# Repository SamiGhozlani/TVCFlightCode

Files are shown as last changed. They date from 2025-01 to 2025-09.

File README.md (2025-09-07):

# TVCFlightCode

Welcome to my Repo for my Thrust Vector Controlled model rocket.\
For my flight computer, I used an Arduino Nano, a BNO055 IMU, a 1528-1462-ND microSD card reader, and an MPM3610 buck converter among other things (see Pcb schematic for more details).\
Attatched is my flight code, the PCB schematic (developed with Altium), and the SolidWorks files.\
Below is a slow-mo of the first nominal flight.

rocket

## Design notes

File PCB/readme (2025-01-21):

# I sent my Gerber Files to JLCPCB for manufacturing

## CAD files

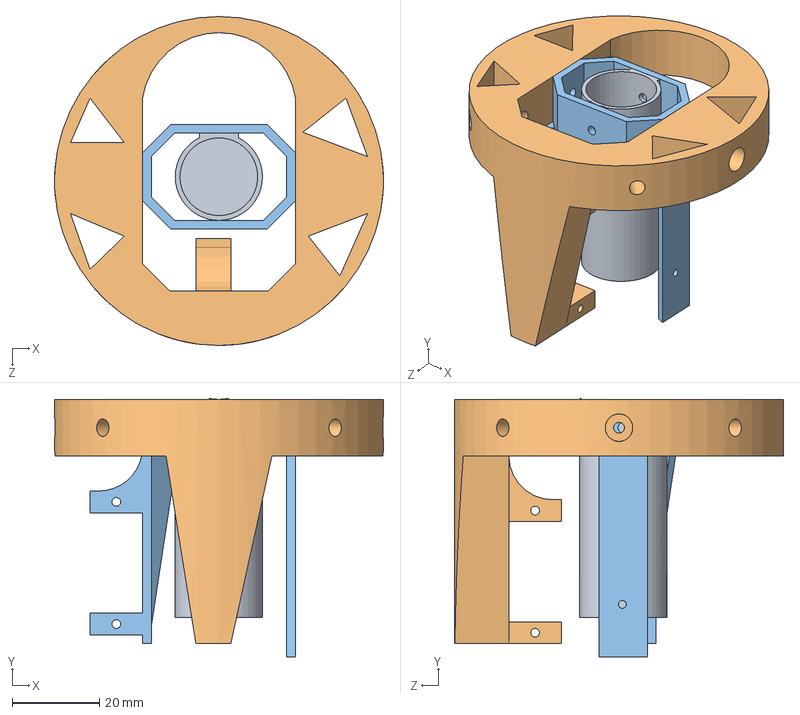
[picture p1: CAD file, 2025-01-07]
SolidWorks/AssemblyTVCMount.SLDASM
75.4 x 59.3 x 75.4 mm
Axis1TVM
Axis2
motorcase2

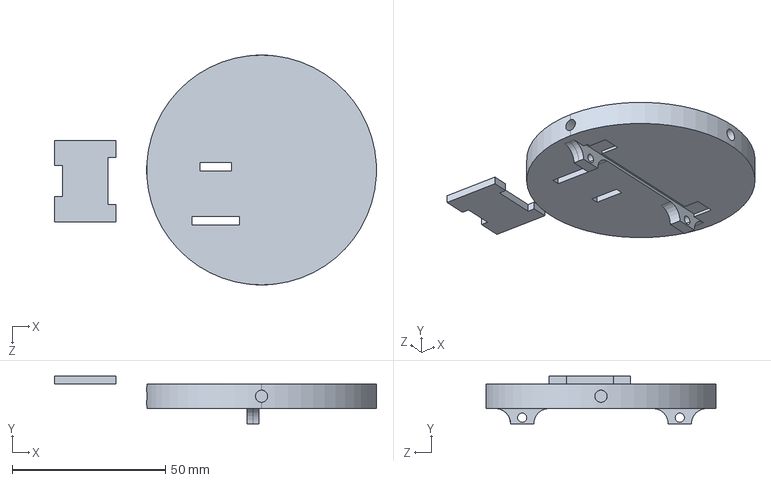
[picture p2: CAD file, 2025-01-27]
SolidWorks/BNOHolderTop.SLDPRT
105.1 x 15.5 x 75.0 mm

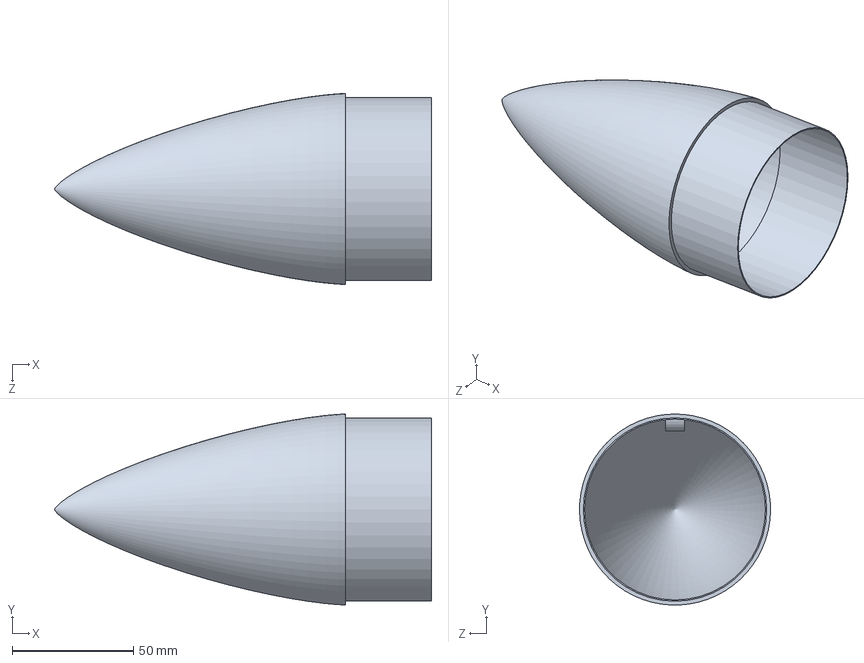
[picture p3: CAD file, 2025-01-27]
SolidWorks/NoseCone.SLDPRT
155.5 x 78.8 x 78.8 mm

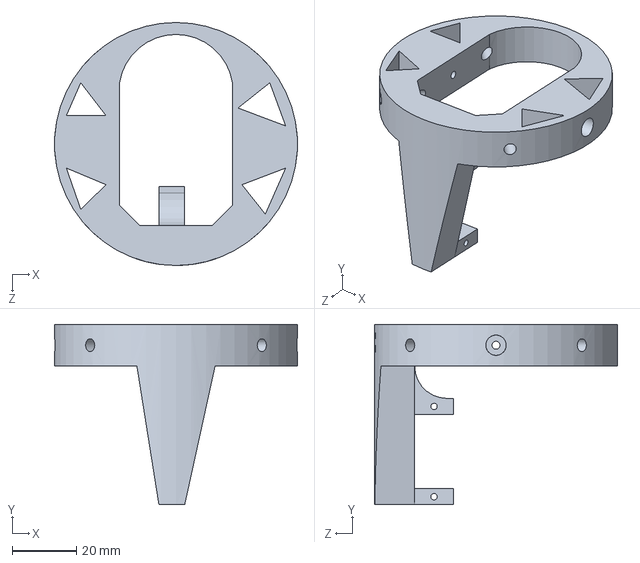
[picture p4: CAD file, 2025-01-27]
SolidWorks/Axis2.SLDPRT
75.4 x 56.0 x 75.4 mm

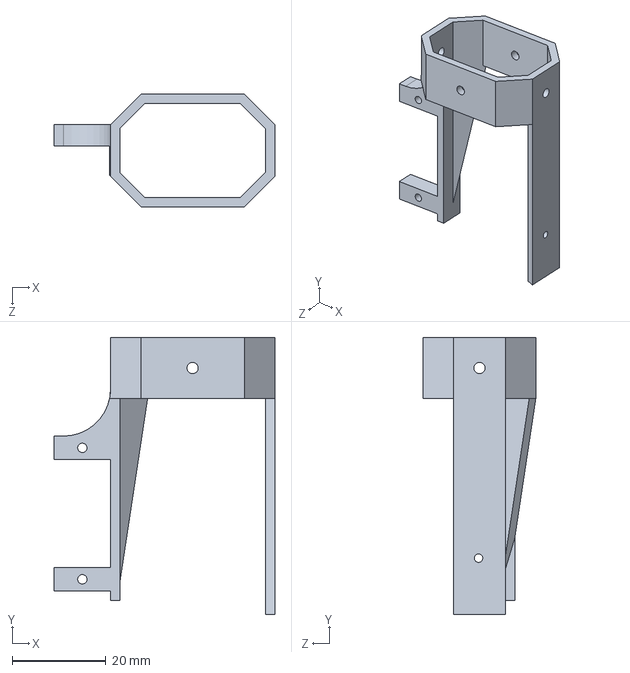
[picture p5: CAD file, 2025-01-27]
SolidWorks/Axis1TVM.SLDPRT
47.0 x 59.0 x 24.0 mm

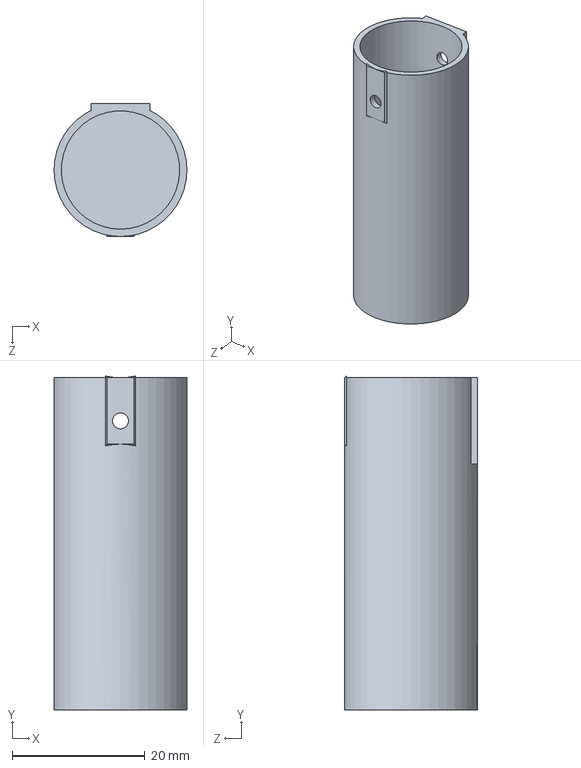
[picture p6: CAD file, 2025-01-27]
SolidWorks/motorcase2.SLDPRT
20.0 x 50.3 x 20.0 mm

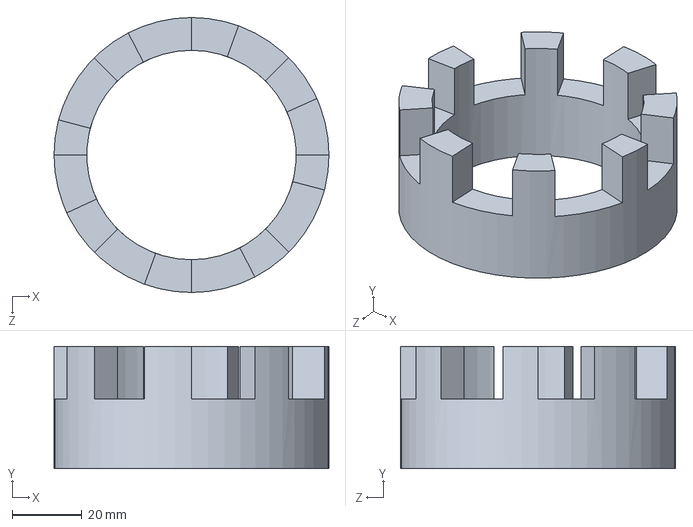
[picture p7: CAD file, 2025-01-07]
SolidWorks/LaunchMount.SLDPRT
78.8 x 35.0 x 78.8 mm

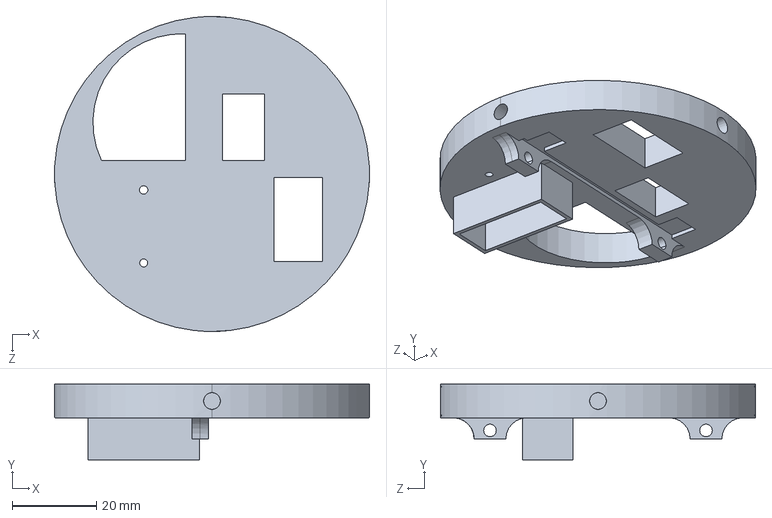
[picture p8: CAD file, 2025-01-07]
SolidWorks/PCBHolderBottom.SLDPRT
75.0 x 18.0 x 75.0 mm

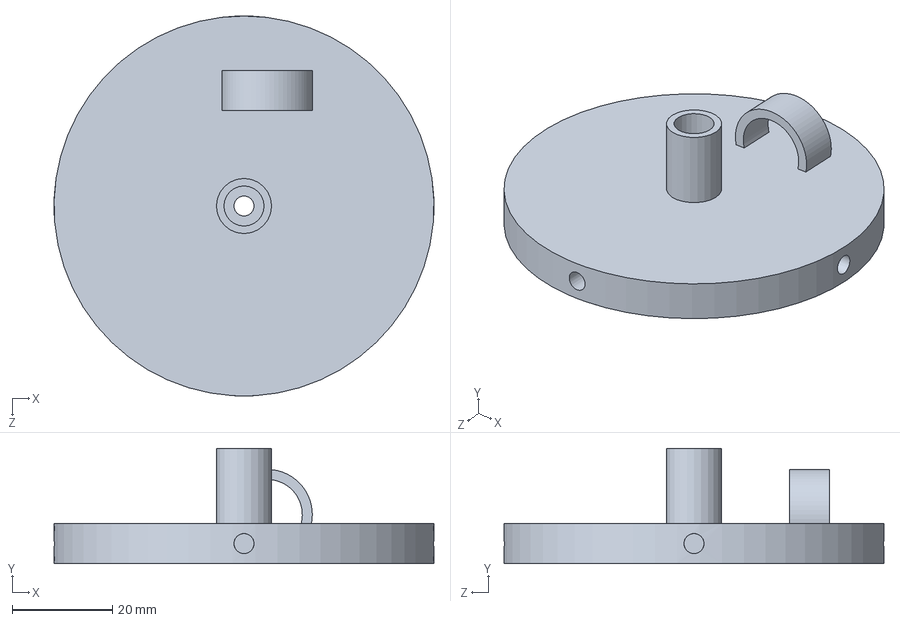
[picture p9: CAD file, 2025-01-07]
SolidWorks/BulkHead.SLDPRT
75.8 x 23.0 x 75.8 mm

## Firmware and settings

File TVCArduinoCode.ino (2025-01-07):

//Sami TVC Mount Code
//Uses PID loop to stabalize pitch and roll axis


//Libraries
#include <Servo.h>
#include <Adafruit_Sensor.h>
#include <Adafruit_BNO055.h>
#include <utility/imumaths.h>
#include <SD.h>

//2 Servos
Servo servoX;
Servo servoY;

//For this project I used the Adafruit BNO055
Adafruit_BNO055 bno = Adafruit_BNO055(55, 0x28, &Wire);

//PID constants
double Kp = 0.6;
double Ki = 0.05;
double Kd = 0.12;

//Error
double error = 0;
double prevErrorY = 0;
double prevErrorZ = 0;
double xOffset = 0;
double yOffset = 0;
int DError = 0;
double iErrorY = 0;
double iErrorZ = 0;
double RADTODEG = 57.2957795;
//Calibrated upright values
int desiredOrientationY = 0;
int desiredOrientationZ = 0;
int firstRound = 0;
double outputCorrection;

//Setting the starting values for the servos
double servoXLocation = 90;
double servoYLocation = 90;
double currentTime = micros();
double previousTimeY = currentTime;
double previousTimeZ = currentTime;
double previousTimeGyro = currentTime;
double dt=0.0001;
double relativeOrientationY = 90;
double relativeOrientationZ = 90; 
bool calibrated = false;
bool launch = false;
bool rotated = false;
double launchTime = 0;
double firingTime = 1800;
int i = 0;
File myFile;
String fileName = "TVC5.txt";
bool fired = false;
int rotation = 0;

void setup() {
  // Setting up the serial
  Serial.begin(115200);
  while (!Serial) {
    delay(10);
  }  
  // Setting up Servo, SD Card and BNO055 locations
  delay(50);
  pinMode(10, OUTPUT);
  
  if(!SD.begin(10)){
    Serial.print("SD Initialization failed");
  }
  Serial.print("SD Initialization Successfull \n");
  myFile = SD.open(fileName, FILE_WRITE);
  if(myFile){
    Serial.print("Writing to " + fileName);
    myFile.println("Time,orientationX,orientationY,servoX,servoY");
    myFile.close();
  }
  
  //pinMode(2, OUTPUT);
  servoX.attach(3);
  servoY.attach(5);
  // Initialise the BNO055 sensor
  if(!bno.begin())
  {
    // Not good: there was a problem detecting the BNO055
    Serial.print("No BNO055 detected ... ");
    while(1);
  }
  servoX.write(50);
  servoY.write(105);
  delay(8000);
  servoX.write(50);
  servoY.write(105);
  delay(1800);
  sensors_event_t event;
  bno.getEvent(&event);
  desiredOrientationY = event.orientation.y;
  desiredOrientationZ = event.orientation.z;

  //Logging calibration values
  myFile = SD.open(fileName, FILE_WRITE);
  myFile.print(millis());
  myFile.print(",");
  myFile.print(desiredOrientationY);
  myFile.print(",");
  myFile.print(desiredOrientationZ);
  myFile.print(",");
  myFile.print(60);
  myFile.print(",");
  myFile.println(100);
  myFile.close();
  
  previousTimeY = micros();
  previousTimeZ = micros();
}

void loop() {
  // Idling while the rocket waits to take off:
  sensors_event_t event;
  bno.getEvent(&event);
  Serial.println(event.acceleration.y);

  // Detecting launch if there is a large enough upwards acceleration
  if (event.acceleration.y <= -6){
    if (launch == false){
      Serial.println("LActivated  ");
      Serial.println("  ");
      launchTime = millis();
      launch = true;
    }
  }
  
  if (launch == true && rotated == false){
    //Start rotating
    desiredOrientationZ += 1;
  }
  //Stop at 30 degrees
  if (desiredOrientationZ >= 30){
    rotated = true;
  }
  
  //Inputting orientation to PID loops
  relativeOrientationY = event.orientation.y;
  relativeOrientationZ = event.orientation.z;
  servoXLocation = 50+2*PIDCorrectionY(0, relativeOrientationY);
  servoYLocation = 110+2*PIDCorrectionZ(desiredOrientationZ, relativeOrientationZ);
  if(servoXLocation > 30 && servoXLocation < 70){
      //Updating Servo Position:
      servoX.write(servoXLocation);
  }
  if(servoYLocation > 90 && servoYLocation < 130){
      //Updating Servo Position:
      servoY.write(servoYLocation);
  }
  
  currentTime = micros();
  
  myFile = SD.open(fileName, FILE_WRITE);
  myFile.print(millis());
  myFile.print(",");
  myFile.print(relativeOrientationY);
  myFile.print(",");
  myFile.print(relativeOrientationZ);
  myFile.print(",");
  myFile.print(servoXLocation);
  myFile.print(",");
  myFile.println(servoYLocation);
  myFile.close();
  
  Serial.println(relativeOrientationY);
  Serial.println(relativeOrientationZ);
  Serial.print("PID Correction_y: ");
  Serial.print(servoXLocation);
  Serial.print("\t PID Correction_z: ");
  Serial.print(servoYLocation);
  Serial.println(dt);
  Serial.println(" ");
}


double PIDCorrectionY (double desiredOrientation, double currentOrientation) {
  currentTime = micros();
  //Converting dt into seconds using a microsecond timestamp
  dt = (currentTime - previousTimeY)/1000000;
  error = desiredOrientation-currentOrientation;
  iErrorY += (desiredOrientation-currentOrientation)*dt;
  if (firstRound > 1){
    DError = (error-prevErrorY)/dt;
    Serial.print("DError: ");
    Serial.println(DError);
    Serial.print("\t");
  }
  else{
    //Removing the Derivative error value from the first loop
    firstRound += 1;
    DError = 0;
  }

  outputCorrection = error*Kp+iErrorY*Ki+DError*Kd;
  //limiting correction if it exceeds Servo limitations
  if (outputCorrection > 10){
    outputCorrection=10;
  }
  if (outputCorrection < -10){
    outputCorrection=-10;
  }
  //Saving error and time for next iteration
  prevErrorY = error;
  previousTimeY = currentTime;
  return outputCorrection;
}

double PIDCorrectionZ (double desiredOrientation, double currentOrientation) {
  currentTime = micros();
  //Converting dt into seconds using a microsecond timestamp
  dt = (currentTime - previousTimeZ)/1000000;
  error = desiredOrientation-currentOrientation;
  iErrorZ += (desiredOrientation-currentOrientation)*dt;
  if (firstRound > 1){
    DError = (error-prevErrorZ)/dt;
  }
  else{
    //Removing the Derivative error value from the first loop
    firstRound += 1;
    DError = 0;
  }

  outputCorrection = error*Kp+iErrorZ*Ki+DError*Kd;
  
  //limiting correction if it exceeds Servo limitations
  
  if (outputCorrection > 10){
    outputCorrection = 10;
  }
  else if (outputCorrection < -10){
    outputCorrection = -10;
  }
  
  //Saving error and time for next iteration
  prevErrorZ = error;
  previousTimeZ = currentTime;
  return outputCorrection;
}

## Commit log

2025-01-07 Uploaded SolidWorks TVC Assembly files
    [AssemblyTVCMount.SLDASM]
2025-01-07 Uploaded Bulkhead SolidWorks file
    [BulkHead.SLDPRT]
2025-01-07 Created folder to store SolidWorks files
    [BulkHead.SLDPRT]
2025-01-07 Moved to SolidWorks folder
    [AssemblyTVCMount.SLDASM]
2025-01-07 Uploaded PCB holder bottom file
    [PCBHolderBottom.SLDPRT]
2025-01-07 Uploaded Launch Mount File
    [LaunchMount.SLDPRT]
2025-01-07 PCB Schematic file
    [TVCPCB.SchDoc]
2025-01-07 TVC PCB File
    [TVCPCB.PcbDoc]
2025-01-21 Move TVCPCB.SchDoc to PCB/TVCPCB.SchDoc
    [TVCPCB.SchDoc]
2025-01-21 Moved TVCPCB.PcbDoc to PCB/TVCPCB.PcbDoc
    [TVCPCB.PcbDoc]
